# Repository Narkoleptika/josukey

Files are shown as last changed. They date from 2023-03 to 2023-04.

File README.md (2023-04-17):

# Josukey

A keyboard for Joey

This is an ergogen based corne clone that I intend to modify and tweak as I descend into the rabbit hole

<p align="center">
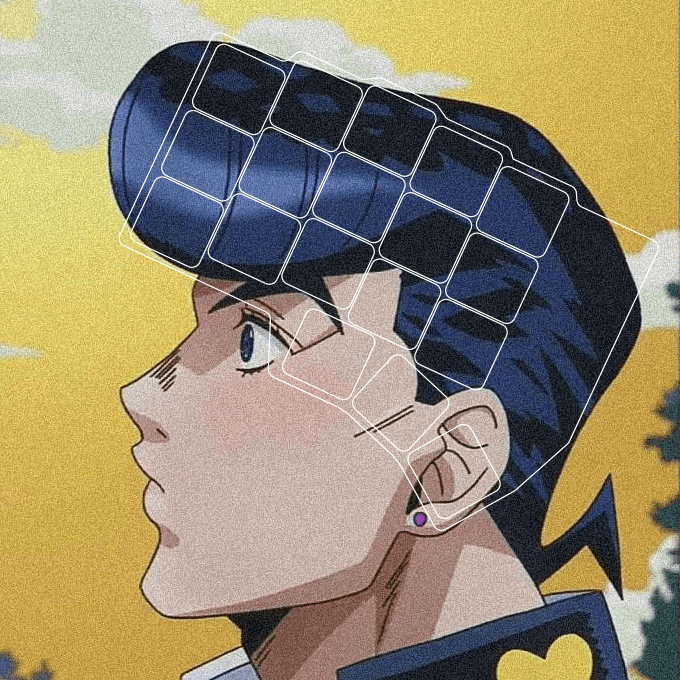
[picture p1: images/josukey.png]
    
</p>

## V1

<p align="center">
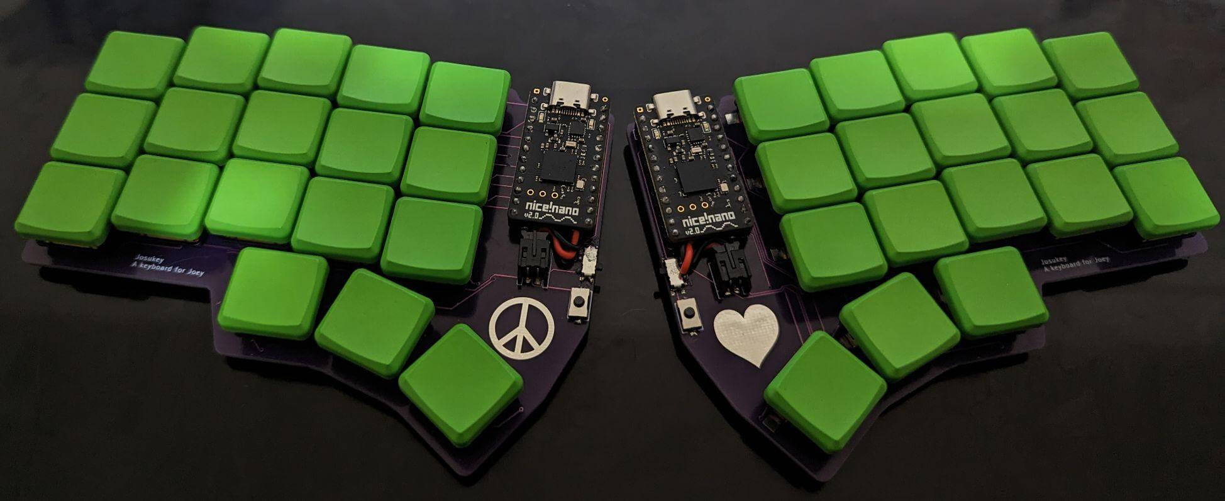
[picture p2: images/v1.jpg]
    
</p>

## Prerequisites

* Node
* Docker
## Getting Started

Get my files on your computer 😏 and install dependencies.

```bash
git clone https://github.com/Narkoleptika/josukey.git
cd josukey
npm i
```

## Ergogen

### Build

This will run Ergogen and build all of the output files.

```bash
npm run ergogen:build
```

### Watch

This will watch the `config.yaml` file and the `footprints` directory and run the build command whenever there are changes.

```bash
npm run ergogen:watch
```

## ZMK

### Init

Downloads ZMK dependencies

```bash
npm run zmk:update
```

### Build

Builds the ZMK firmware

```bash
npm run zmk:build
```

### Down

Shuts down the ZMK docker services

```bash
npm run zmk:down
```

## Thanks

* <a href="https://github.com/ergogen/ergogen" target="_blank">Ergogen</a>
* <a href="https://discord.gg/nbKcAZB" target="_blank">Absolem Club Discord</a>
* <a href="https://github.com/tsteffek/Ergogen-V4-Migration-Guide" target="_blank">V4 Migration Guide</a>
* <a href="https://gitlab.com/Audijo/keyboard" target="_blank">Claw</a>
* <a href="https://github.com/MrCarney/mrkeyboard" target="_blank">MrKeyboard</a>
* <a href="https://github.com/foostan/crkbd" target="_blank">Corne keyboard</a>
* <a href="https://github.com/zmkfirmware/zmk" target="_blank">ZMK</a>
* <a href="https://github.com/manna-harbour/miryoku_zmk" target="_blank">Miryoku ZMK</a>

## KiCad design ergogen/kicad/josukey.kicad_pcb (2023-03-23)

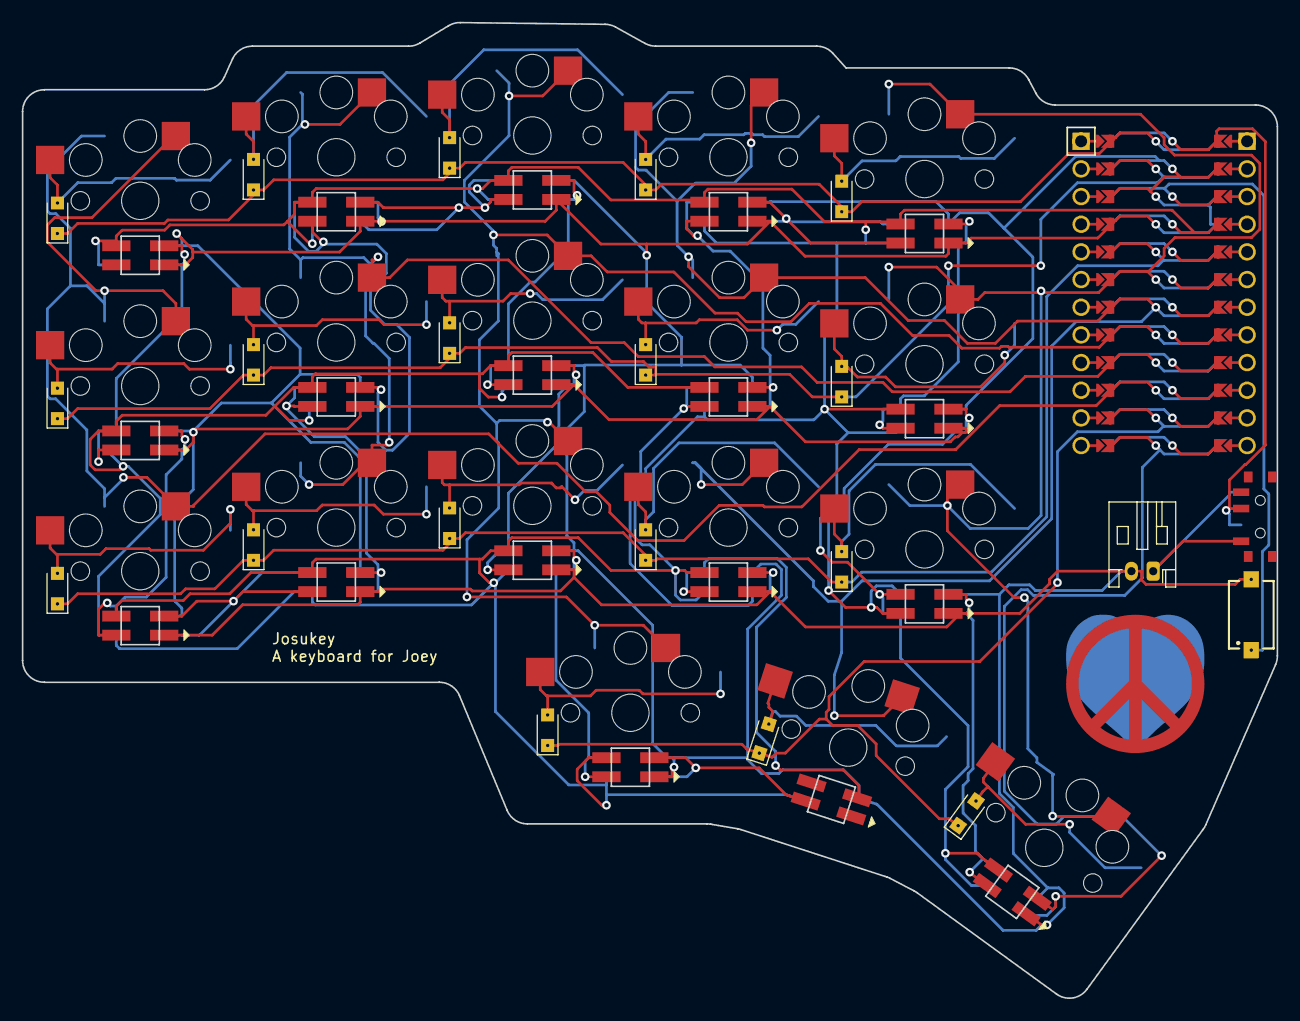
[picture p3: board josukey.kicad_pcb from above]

Board: 2 copper layers, 115.2 x 89.6 mm, 58 parts (0 on the bottom side), 50 nets.

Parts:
D1, D2, D3, D4, D5, D6, D7, D8, D9, D10, D11, D12, D13, D14, D15, D16, D17, D18: Nexperia_CFP3_SOD-123W
LED1, LED2, LED3, LED4, LED5, LED6, LED7, LED8, LED9, LED10, LED11, LED12, LED13, LED14, LED15, LED16, LED17, LED18: WS2812B
MCU1: ProMicro
S1, S2, S3, S4, S5, S6, S7, S8, S9, S10, S11, S12, S13, S14, S15, S16, S17, S18: PG1350
S19: 434121025816
T1: SW_SPDT_PCM12
_1: JST_PH_S2B-PH-K_1x02_P2.00mm_Horizontal

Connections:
GND: LED1.3, LED2.3, LED3.3, LED4.3, LED5.3, LED6.3, LED7.3, LED8.3, LED9.3, LED10.3, LED11.3, LED12.3, LED13.3, LED14.3, LED15.3, LED16.3, LED17.3, LED18.3, MCU1.2, MCU1.21, MCU1.22, S19.2, _1.2
P0: D2.1, D5.1, D8.1, D11.1, D14.1, MCU1.23
P1: D3.1, D6.1, D9.1, D12.1, D15.1, MCU1.24
P2: D1.1, D4.1, D7.1, D10.1, D13.1, MCU1.20
P3: MCU1.19, S13.1, S14.1, S15.1, S18.1
P4: MCU1.18, S10.1, S11.1, S12.1, S17.1
P5: MCU1.17, S7.1, S8.1, S9.1, S16.1
P6: MCU1.16, S4.1, S5.1, S6.1
P7: MCU1.15, S1.1, S2.1, S3.1
P8: D16.1, D17.1, D18.1, MCU1.14
P9: LED18.4, MCU1.13
RAW: MCU1.1, T1.2
RST: MCU1.3, S19.1
VCC: LED1.1, LED2.1, LED3.1, LED4.1, LED5.1, LED6.1, LED7.1, LED8.1, LED9.1, LED10.1, LED11.1, LED12.1, LED13.1, LED14.1, LED15.1, LED16.1, LED17.1, LED18.1, MCU1.4
main_index_bottom: D10.2, S10.2
main_index_home: D11.2, S11.2
main_index_top: D12.2, S12.2
main_inner_bottom: D13.2, S13.2
main_inner_home: D14.2, S14.2
main_inner_top: D15.2, S15.2
main_middle_bottom: D7.2, S7.2
main_middle_home: D8.2, S8.2
main_middle_top: D9.2, S9.2
main_pinky_bottom: D1.2, S1.2
main_pinky_home: D2.2, S2.2
main_pinky_top: D3.2, S3.2
main_ring_bottom: D4.2, S4.2
main_ring_home: D5.2, S5.2
main_ring_top: D6.2, S6.2
pos: T1.1, _1.1
rgb_main_index_bottom: LED10.4, LED11.2
rgb_main_index_home: LED11.4, LED12.2
rgb_main_index_top: LED12.4, LED15.2
rgb_main_inner_bottom: LED13.4, LED18.2
rgb_main_inner_home: LED13.2, LED14.4
rgb_main_inner_top: LED14.2, LED15.4
rgb_main_middle_bottom: LED7.4, LED16.2
rgb_main_middle_home: LED7.2, LED8.4
rgb_main_middle_top: LED8.2, LED9.4
rgb_main_pinky_bottom: LED1.4, LED4.2
rgb_main_pinky_home: LED1.2, LED2.4
rgb_main_pinky_top: LED2.2, LED3.4
rgb_main_ring_bottom: LED4.4, LED5.2
rgb_main_ring_home: LED5.4, LED6.2
rgb_main_ring_top: LED6.4, LED9.2
rgb_thumb_home_home: LED10.2, LED17.4
rgb_thumb_inner_home: LED16.4, LED17.2
thumb_home_home: D17.2, S17.2
thumb_inner_home: D16.2, S16.2
thumb_outer_home: D18.2, S18.2

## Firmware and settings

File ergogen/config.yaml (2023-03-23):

points:
    key.padding: cy
    zones:
        main:
            rows:
                bottom.row_net: P2
                home.row_net: P0
                top.row_net: P1
            columns:
                pinky:
                    key:
                        col_net: P7
                        spread: cx
                    rows:
                        bottom:
                            led_in: "rgb_{{name}}"
                            led_out: rgb_main_pinky_home
                        home:
                            led_in: "rgb_{{name}}"
                            led_out: rgb_main_pinky_top
                        top:
                            led_in: "rgb_{{name}}"
                ring:
                    key:
                        col_net: P6
                        stagger: 4
                        spread: cx
                    rows:
                        bottom:
                            led_in: "rgb_{{name}}"
                            led_out: rgb_main_pinky_bottom
                        home:
                            led_in: "rgb_{{name}}"
                            led_out: rgb_main_ring_bottom
                        top:
                            led_in: "rgb_{{name}}"
                            led_out: rgb_main_ring_home
                middle:
                    key:
                        col_net: P5
                        stagger: 2
                        spread: cx
                    rows:
                        bottom:
                            led_in: "rgb_{{name}}"
                            led_out: rgb_main_middle_home
                        home:
                            led_in: "rgb_{{name}}"
                            led_out: rgb_main_middle_top
                        top:
                            led_in: "rgb_{{name}}"
                            led_out: rgb_main_ring_top
                index:
                    key:
                        col_net: P4
                        stagger: -2
                        spread: cx
                    rows:
                        bottom:
                            led_in: "rgb_{{name}}"
                            led_out: rgb_thumb_home_home
                        home:
                            led_in: "rgb_{{name}}"
                            led_out: rgb_main_index_bottom
                        top:
                            led_in: "rgb_{{name}}"
                            led_out: rgb_main_index_home
                inner:
                    key:
                        col_net: P3
                        stagger: -2
                        spread: cx
                    rows:
                        bottom:
                            led_in: "rgb_{{name}}"
                            led_out: rgb_main_inner_home
                        home:
                            led_in: "rgb_{{name}}"
                            led_out: rgb_main_inner_top
                        top:
                            led_in: "rgb_{{name}}"
                            led_out: rgb_main_index_top
        thumb:
            anchor:
                ref: main_index_bottom
                shift: [-0.5cx, -cy]
            rows.home.row_net: P8
            columns:
                inner.key:
                    col_net: P5
                    led_in: "rgb_{{name}}"
                    led_out: rgb_main_middle_bottom
                    spread: cx
                home.key:
                    col_net: P4
                    led_in: "rgb_{{name}}"
                    led_out: rgb_thumb_inner_home
                    spread: cx + 2
                    rotate: -18
                    stagger: -3.2
                outer.key:
                    col_net: P3
                    led_in: P9
                    led_out: rgb_main_inner_bottom
                    spread: cx
                    rotate: -36
                    stagger: -9.2
outlines:
    _board_outline:
        -   what: polygon
            fillet: 2
            points:
                -   ref: thumb_outer_home
                    shift: [0.6cx, 0.6cy]
                -   ref: thumb_outer_home
                    shift: [0.6cx, -0.6cy]
                -   ref: thumb_outer_home
                    shift: [-0.4cx, -0.6cy]

                -   ref: thumb_home_home
                    shift: [0.4cx, -0.6cy]
                -   ref: thumb_home_home
                    shift: [-0.4cx, -0.6cy]

                -   ref: thumb_inner_home
                    shift: [0.4cx, -0.6cy]
                -   ref: thumb_inner_home
                    shift: [-0.6cx, -0.6cy]

                -   ref: main_pinky_bottom
                    shift: [1.6cx, -0.6cy]
                -   ref: main_pinky_bottom
                    shift: [0.6cx, -0.6cy]
                -   ref: main_pinky_bottom
                    shift: [-0.6cx, -0.6cy]

                -   ref: main_pinky_top
                    shift: [-0.6cx, 0.6cy]
                -   ref: main_pinky_top
                    shift: [0.4cx, 0.6cy]

                -   ref: main_ring_top
                    shift: [-0.5cx, 0.6cy]
                -   ref: main_ring_top
                    shift: [0.4cx, 0.6cy]

                -   ref: main_middle_top
                    shift: [-0.4cx, 0.61cy]
                -   ref: main_middle_top
                    shift: [0.4cx, 0.6cy]

                -   ref: main_index_top
                    shift: [-0.4cx, 0.6cy]
                -   ref: main_index_top
                    shift: [0.5cx, 0.6cy]

                -   ref: main_inner_top
                    shift: [-0.4cx, 0.6cy]
                -   ref: main_inner_top
                    shift: [0.5cx, 0.6cy]

                -   ref: main_inner_top
                    shift: [0.6cx, 0.4cy]
                -   ref: main_inner_top
                    shift: [1.8cx, 0.4cy]
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

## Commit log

2023-03-12 add initial round of kicad files
    [josukey.kicad_pcb]
2023-03-13 add text and include images in ergogen config
    [josukey.kicad_pcb]
2023-03-23 Restore former logo size. Update kicad with autorouted pcb
    [josukey.kicad_pcb]
2023-04-17 Move ergogen to subdir
    [josukey.kicad_pcb]
